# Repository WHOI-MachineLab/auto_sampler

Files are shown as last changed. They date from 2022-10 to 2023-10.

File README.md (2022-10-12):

# Open Source Engineered Autonomous Sampler (OpenSEAS)
## MACHINE Lab, Woods Hole Oceanographic Institution
Ryan C. Galusha: 2022 Summer Student Fellow, WHOI  
Samuel Koeck: Research Assistant, WHOI  
Solomon T. Chen: MIT/WHOI JP Student  
Matthew H. Long: Department of Marine Chemistry and Geochemistry, WHOI  

----
## File Descriptions
###### <OpenSEAS_interval.ino>
This code triggers the first sampling event at a user specified time. All subsequent sampling events occur at a regular time interval.  

A note regarding the Servo.h Arduino IDE library...  
This library is written to tell a servo motor to write to a specific position from 0 to 180 degrees ONLY. Some servo motors have the ability to rotate well beyond 180 degrees, including the goBILDA Stingray-4 being used on this project. For these servos, programming with the Aruduino library can be unintuitive because telling the servo to write to position 180 actually results in the servo rotating to its maximum point of rotation. For this reason, a global constant integer, "convertDegrees" is included to convert from "Aduino IDE degrees" to actual degrees of rotation. For example, the maximum rotation allowed by the Stingray-4 is 450 degrees, so "Arduino IDE degrees" are multiplied by the ratio 450/180 to convert to actual degrees.

###### <OpenSEAS_bench-test.ino>
To be used for calibrating the servo motor to the specific position requirements of each valve port. This code samples from a single valve position to allow for a determination of the repeatability of fluid volumes at each sample port. Sample port 4 is named as the "home position" due to constraints in the way that the valve and servo motor are mounted to the housing.

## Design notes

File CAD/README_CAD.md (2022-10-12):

# CAD File Descriptions

###### <OpenSEAS_housing.step>
3D-printed underwater housing for the pump, servo gearbox, 10-position valve, and electronics. Includes the main housing body where components live. Requires three O-rings: one radial-rod seal at the valve surface and two radial-piston seals at the bulkhead. Sizing for O-rings are included in the Datasheets directory.

###### <OpenSEAS_bulkhead.step>
3D-printed bulkhead for teh underwater housing. Includes two 1/4 - 28 fluid passthroughs for the pump tubing. Additionally, one electronics passthrough (SubConn) is included if external power/communications are desired.

###### <OpenSEAS_gear-mount-hardware.step>
3D-printed mounting hardward for attaching the gearbox to the underwater housing.

###### <Components/goBILDA_Stingray-4.STEP.zip>
Preconfigured servo motor and gear box for rotation of the valve mechanism, obtained from [ServoCity] (https://www.servocity.com/stingray-4-servo-gearbox-0-68-sec-60-15-rpm-1400-oz-in-torque-450-rotation/). Note, this file is stored as a compressed .zip file because the original .STEP file is too large to upload to GitHub.

###### <Components/goBILDA_D-bore-hub.STEP>
1/4 inch D-bore shaft adapter for connecting the gear box to the 10-position valve shaft, obtained from [ServoCity] (https://www.servocity.com/1309-series-sonic-hub-1-4-d-bore/). This component is attached to the gear box with four screws, before mounting to the valve shaft. Care should be taken to ensure there is enough clearance between these mounting screws and the valve mounting screws during operation. 

###### <Components/Sykam _S-6151.STEP>
10 position HPLC valve (Model: Sykam S 6151) for selecting the desire sample bag port, obtained from [Sykam] (https://sykam.com/product/valves/s-6151-hplc-valve/).

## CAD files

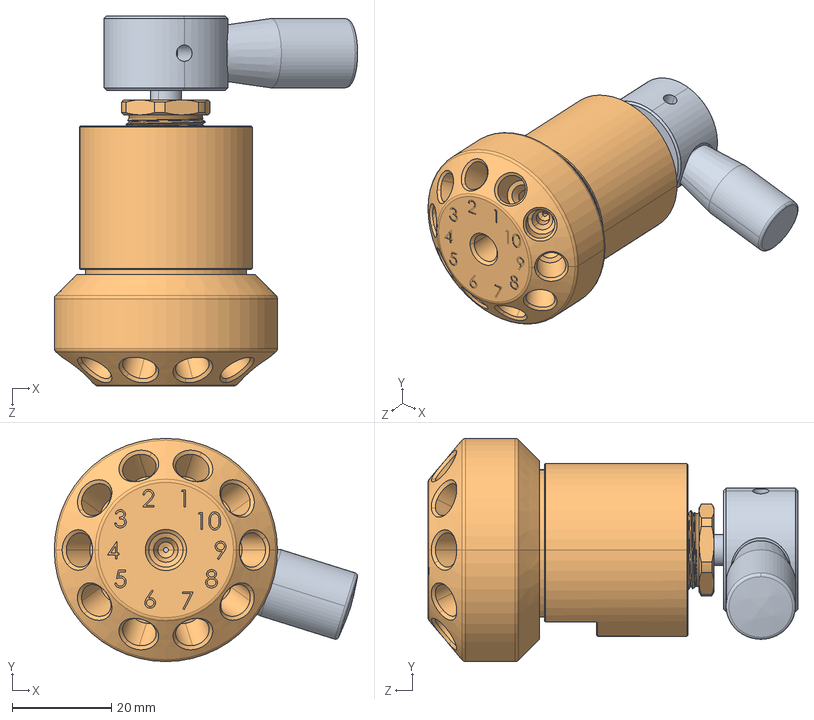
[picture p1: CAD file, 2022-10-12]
CAD/Components/Sykam _S-6151.STEP
61.2 x 45.0 x 74.6 mm

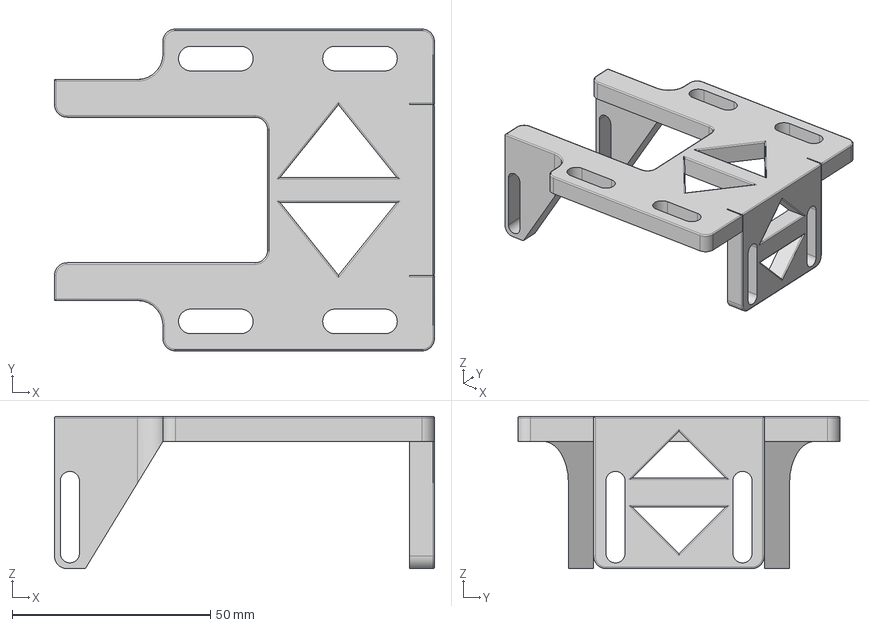
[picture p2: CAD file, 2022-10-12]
CAD/OpenSEAS_gear-mount-hardware.step
95.7 x 81.1 x 38.4 mm

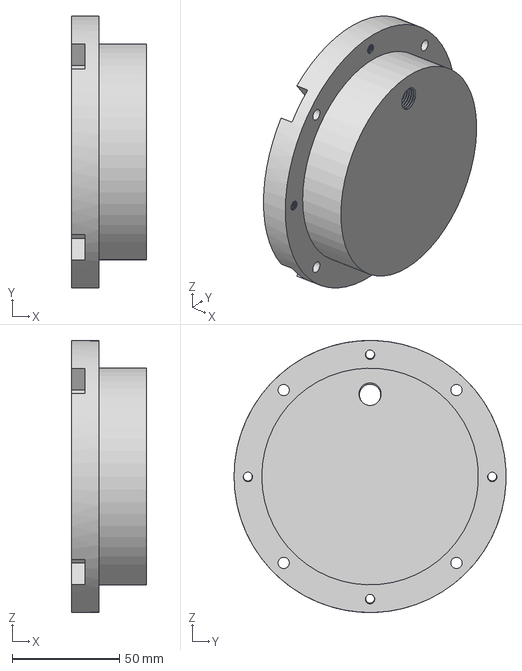
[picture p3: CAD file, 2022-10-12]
CAD/OpenSEAS_Bulkhead.step
34.9 x 126.9 x 127.0 mm

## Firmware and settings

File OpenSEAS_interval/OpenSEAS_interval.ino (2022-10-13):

// Original version of code developed August 2022, Ryan C. Galusha, WHOI MACHINE Lab
// This code triggers the first sampling event at a user specified time defined in the structure: 'FirstSample'
// All subsequent sampling events occur at a regular time interval specified by the constant int: 'SampleInterval'

#include <TimeLib.h>
#include <TimeAlarms.h>
#include <Servo.h>

const int n_samples = 10; // Define number of samples you plan to take (maximum: 10)

struct Schedule {
  int Day;
  int Hour;
  int Minute;
};

Schedule FirstSample = {DAY, HOUR , MIN}; // Define the day of month (1-31) and time of day for the first sample to be triggered
  const int SampleInterval = 3600; // Define the regular interval between all remaining samples here (units: seconds)

  //Servo constants & variables
  Servo gearbox; // name the servo "gearbox"
  const int convertDegrees = 450/180; // ratio for converting from Servo.h library to the actual degrees rotated. See README for more info.
  const int zero = 12.5 * convertDegrees; // calibrated "zero" position for the first valve position
  const int rotationDegrees =  40 * convertDegrees; // calibrated displacement of servo to reach the next valve position

  // Define which pins are attached to components here
  const int pumpPin = 6;
  const int servoPin = 23;

  void setup()
  { 
    // LED pin set to output (for diagnostics)
    pinMode(13, OUTPUT);

    // set the Time library to use Teensy internal clock to keep time
    setSyncProvider(getTeensyTime); // see "void getTeensyTime()" function below

    // Verify that real time clock has been set
    Serial.begin(115200);
    if (timeStatus() != timeSet) {
      Serial.println("Unable to sync with the RTC");
      // LED flash here
    } else {
      Serial.println("RTC has set the system time");
      // Long LED on
    }

    // Verify that a valid sample number has been entered
    if (n_samples > 10) {
      Serial.println("Program exceeds the maximum number of allowed samples!");
      Serial.println("Please reprogram 'n_samples' to a value of 10 or less");
      while (1) {
        // LED flash here
      }
    }

    // Initialize component pins
    pinMode(pumpPin, OUTPUT);
    gearbox.attach(servoPin);

    // Write the servo position to calibrated "zero" (define above)
    Alarm.delay(5000);
    gearbox.write(zero);
    Alarm.delay(10000);
    
    int samples_taken = 0; // number of samples taken so far
    zero();
    Serial.println("the servo is done zeroing...");
  }

  void loop()
  {
    if (day() == FirstSample.Day && hour() == FirstSample.Hour && min() == FirstSample.Minute && second() < 3)
    {
      SampleNow(); // Collect the first sample
      Alarm.timerRepeat(SampleInterval, SampleNow); // Timer that triggers all subsequent samples after the first sample
    }
    Alarm.delay(1000);
  }

  time_t SampleNow() // Function for every sampling event, returns the timestamp of the sample
  {
    const int pumpTime = 30000; // Define the length of time the pump will be turned to collect each sample (units: ms)

    if (samples_taken < n_samples) {
      Serial.println("Begin sampling routine");

      if (samples_taken != 0) {
        // Tell the servo to turn to the next position
        int nextpos = gearbox.read() + rotationDegrees;
        Serial.println(nextpos);
        gearbox.write(nextpos);
      }
      Alarm.delay(2000); // wait for servo to move to next position

      digitalWrite(pumpPin, HIGH); // turn on pump
      Alarm.delay(pumpTime); // wait to deliver volume (set this time above)
      digitalWrite(pumpPin, LOW); // turn off pump

      samples_taken++;

      Serial.print("Last sample finished at: "); Serial.println(now());
      Serial.print("Samples taken so far: "); Serial.println(samples_taken);

      return now();
    }
  }
  int valve_postition;
  int sample(int valve_new){
    //you will tell the servo which valve to go to.
    return valve_position;
    };
  }
  void zore(){//let's say you lost power and need to reboot};
  time_t getTeensyTime()
  {
    return Teensy3Clock.get();
  }

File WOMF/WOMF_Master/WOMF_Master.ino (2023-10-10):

#include <TimeLib.h>
#include <Servo.h>
#include <SD.h>
#include <SPI.h>
#include <EEPROM.h>

Servo gearbox;

//CHANGE ONLY THIS INFO
int hour_interval=0; //define the sample intervals (time between samples)
int minute_interval=8; //(must be at least five minutes)
const int hour_till_sample=0; //define when you want sampling to start (change hours and/or minutes)
const int minute_till_sample=15;
//

const int servo_pin = 23;
const int pump_pin=13;
float sample_coordinate[10] = {5.3,20.96,36.7,52.4,68.1,83.8,99.6,115.3,131,146.7};
int sample_schedule[2][10];
int i=0;

//This is the SD card variable block
File myFile;
char filename[24];
String newFileName;
String dateStamp;
const int chipSelect = BUILTIN_SDCARD;
String header = "port start end";

//This is the EEPROM variable block
unsigned int address = 0;
int eeprom_value;
int term_address;
int n = 1;
const int BUFFER_SIZE = 100;
char SrfMsg[BUFFER_SIZE];
int rlen;

void setup() {
  // put your setup code here, to run once:

 //Reading and updating EEPROM for naming file
  eeprom_read();
  eeprom_update();
  Serial.print("EEPROM ID is: ");
  Serial.println(eeprom_value);

// put your setup code here, to run once:
  gearbox.attach(servo_pin);
  //set time library to use internal RTC to keep time
  setSyncProvider(getTeensyTime);
 // Verify that RTC has been set
  Serial.begin(9600);

 if (timeStatus() != timeSet) {
    Serial.println("Unable to sync with the RTC");
  } else {
    Serial.println("RTC has set the system time");
  }
  get_sample_schedule(hour_interval,minute_interval);

getDateName();
  createDateName();

//Initialize SD card, create a file, and write header line
  Serial.print("Initializing SD card...");
  if (!SD.begin(chipSelect)) {
    Serial.println("initialization failed!");
    while (1);
  } else {
    Serial.println("initialization done.");
  }
  newFileName.toCharArray(filename, 24);
  myFile = SD.open(filename, FILE_WRITE);
  myFile.println(header);
  Serial.print("Header line = ");Serial.println(header);
  myFile.close();
  Serial.print("File name is: ");
  Serial.println(newFileName);

  pinMode(pump_pin, HIGH);

  Serial.println(sample_schedule[1][i]);
  Serial.println(minute());
}



void loop() {

  // listen for serial message
  if (Serial.available()) {
    int rlen = Serial.readBytesUntil('\r', SrfMsg, BUFFER_SIZE);

    // type 1 to serial monitor to start pump
    if (SrfMsg[0] == '1') {
      Serial.println("pump on");
      digitalWrite(pump_pin, HIGH);
    }
      // type 0 to stop pump
    if (SrfMsg[0] == '0') {
      Serial.println("pump off");
      digitalWrite(pump_pin, LOW);
    }
  }
    while((hour() != sample_schedule[0][i])){
    
        Serial.println("waiting for sampling");
        delay(60000);
    }
  //while(minute() <= 4){} // avoid messing up Aaron's hydrophone? 
  if (minute()==sample_schedule[1][i]){
    Serial.println("It is time, turn the servo and sample");
    Serial.print("Sampling port ");
    Serial.println(i+1);
    myFile = SD.open(filename, FILE_WRITE);
    myFile.print(i+1);
    myFile.print(ts());myFile.print(",");
    turn_valve(sample_coordinate[i]);
    pump_sample(5,0); //pump_sample(minute, second);
    myFile.print(ts());myFile.println();
    i = i+1;
      if(i >= 10){
    Serial.println("Sampling is done, putting teensy to idle");
    while(1){}
    }
  delay(1000);
  }else{
    Serial.println("waiting for sampling");
    delay(5000);
  }
}


void pump_sample(int pump_min, int pump_sec){
  unsigned long millis_now = millis();
  int target = millis_now + pump_min*60*1000 + pump_sec*1000;
  digitalWrite(pump_pin, HIGH);
  while(millis() <= target){
    Serial.print("...");
    delay(5000);
    }
  digitalWrite(pump_pin, LOW);
  }

void turn_valve(float degree){
  gearbox.write(degree);;
  delay(15000);
  }

void get_sample_schedule(int hr_interval,int min_interval) { //constructs the sample schedule that the WOMF will run by
  const int start_time[2] = {hour()+hour_till_sample,minute()+minute_till_sample};
  if (start_time[1]>=60){
    sample_schedule[0][0] = start_time[0]+1;
    sample_schedule[1][0] = start_time[1]-60;
  }else{
    sample_schedule[0][0] = start_time[0];
    sample_schedule[1][0] = start_time[1];  
  }
  
  int hour_marker = sample_schedule[0][0];
  int minute_marker = sample_schedule[1][0];
  Serial.print(hour_marker);
  Serial.print(":");
  Serial.print(minute_marker);
  for(int counter=1; counter<=9; counter++) {
    if(hour_marker + hr_interval >=24) {
      hour_marker = hour_marker + hr_interval;
      sample_schedule[0][counter] = {hour_marker - 24};
    }else{
      hour_marker = hour_marker + hr_interval;
      sample_schedule[0][counter] = {hour_marker};
    }
    if(minute_marker + min_interval >=60) {
     
      minute_marker = minute_marker + minute_interval;
      minute_marker=minute_marker-60;
      sample_schedule[0][counter]={sample_schedule[0][counter]+1};
      sample_schedule[1][counter]={minute_marker};

      hour_marker = hour_marker + 1;
    }else{
      minute_marker = minute_marker + min_interval;
      //sample_schedule[0][counter]={hour_marker};
      sample_schedule[1][counter]= {minute_marker};
    }
    Serial.print(",");
    //Serial.print(now());
    Serial.print(sample_schedule[0][counter]);
    Serial.print(":");
    Serial.print(sample_schedule[1][counter]);
    }
  Serial.println();
  }
  
void digitalClockDisplay() {
  // digital clock display of the time
  Serial.print(hour());
  Serial.print(minute());
  Serial.print(second());
  Serial.print(" ");
  Serial.print(day());
  Serial.print(" ");
  Serial.print(month());
  Serial.print(" ");
  Serial.print(year());
  Serial.println();
}

void getDateName() { //this function grabs date stamp for file name.
  dateStamp = String(month()) + "-" + String(day());
}

void createDateName() { //this function creates new name for each file.
  newFileName = String("WOMF" + dateStamp + "-" + String(eeprom_value) + ".txt");
}

String ts() { //this function grabs local time for timestamp.
  String rn;
  rn = String(hour()) + ":" + String(minute()) + ":" + String(second()) + " " + String(month()) + "/" + String(day()) + "/" + String(year());
  return rn;
}

void eeprom_read() {
  Serial.println("reading eeprom");
  while (address < EEPROM.length() & EEPROM.read(address) != 0) {
    eeprom_value = eeprom_value + EEPROM.read(address);
    address = address + 1;
  }
  term_address = address - 1;
}

void eeprom_update() {
  int last_byte = EEPROM.read(term_address);
  if (last_byte > 255) {
    EEPROM.write(term_address, last_byte + 1);
  }
  else {
    EEPROM.write(term_address + 1, EEPROM.read(term_address + 1) + 1);
  }
  Serial.println("updating done");
}

time_t getTeensyTime(){
  return Teensy3Clock.get();
  }

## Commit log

2022-10-04 Reorganized SampleNow() function; Added convertDegrees for more intuitive servo positioning
2022-10-05 adding zero() and sample(int valve_new) for Ryan to work on 10052022 1118AM
2022-10-05 add CAD folder
2022-10-05 Adding CAD folder and a README.txt inside
2022-10-12 Created OpenSEAS_bench-test.ino for specific valve port testing
2022-10-12 Imported all CAD files and datasheets
    [OpenSEAS_Bulkhead.step, OpenSEAS_gear-mount-hardware.step, Sykam _S-6151.STEP]
2023-10-10 Revert "Name change"
    This reverts commit ce8ef957ccf719e34d3e9de13dcc81d89c0205cc.
    [WOMF_Master.ino]
2023-10-10 sample time to 5 mins
2023-10-10 sample interval
